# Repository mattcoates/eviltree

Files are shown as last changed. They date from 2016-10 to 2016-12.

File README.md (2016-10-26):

# Yuletronics: Electronics Club Project Michalmas 2016

This repository contains the example Yuletronics project for Electronics Club. 
You can either use git to clone it, or simply download it 
[here](https://github.com/adamgreig/yuletronics/archive/master.zip).

You'll need KiCAD to open and edit the PCB: [download it 
here](http://kicad-pcb.org/). If you can easily get a nightly build, they have 
a few nice new features.

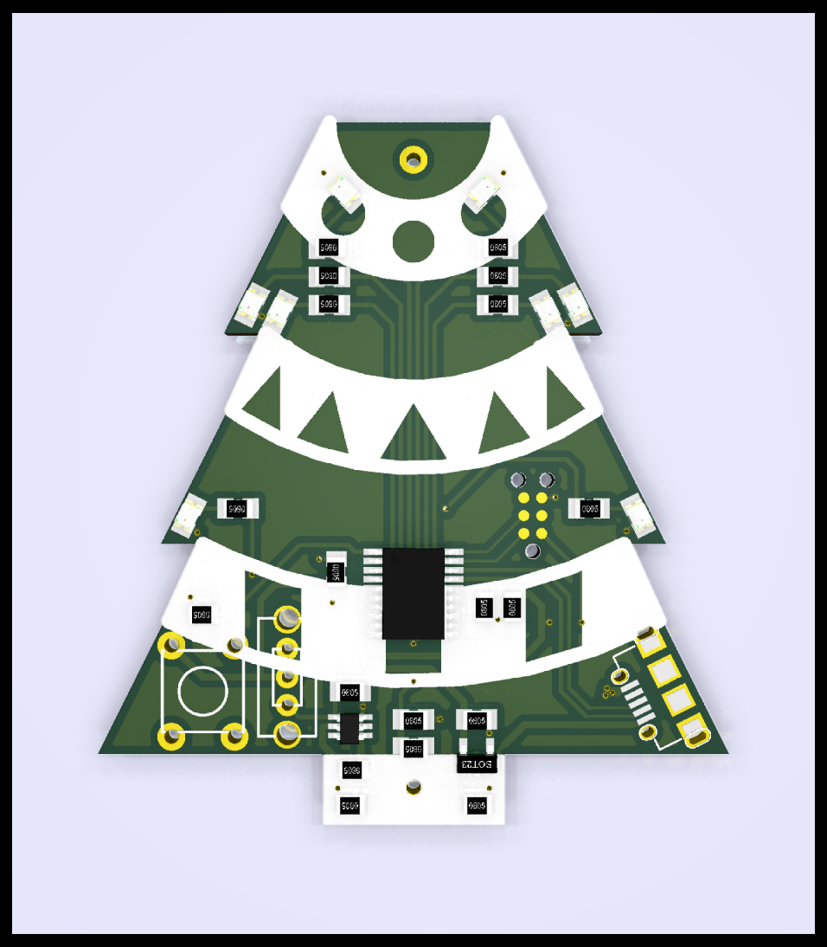
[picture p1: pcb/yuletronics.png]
3d render


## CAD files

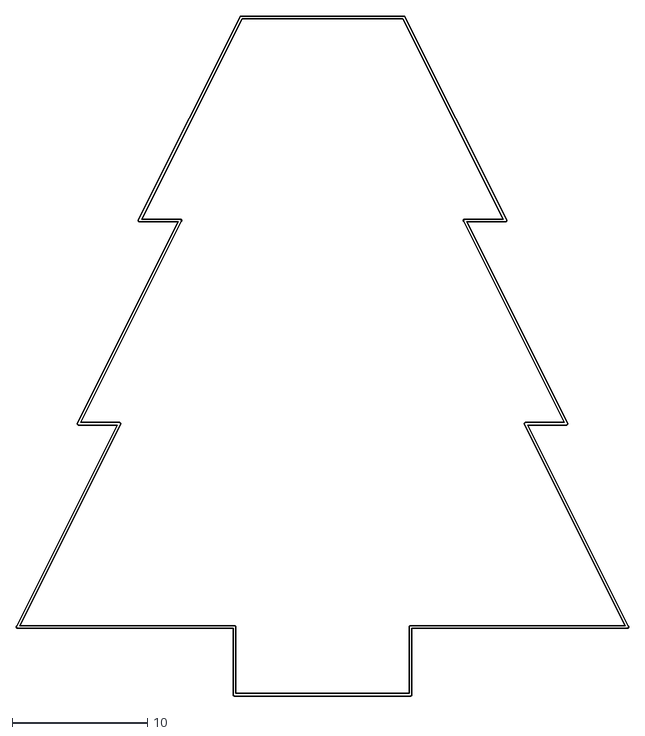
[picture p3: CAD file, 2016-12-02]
pcb/gerbers/yuletronics-Edge.Cuts.dxf
45.2 x 50.2

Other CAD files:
pcb/gerbers/yuletronics-F.Paste.dxf

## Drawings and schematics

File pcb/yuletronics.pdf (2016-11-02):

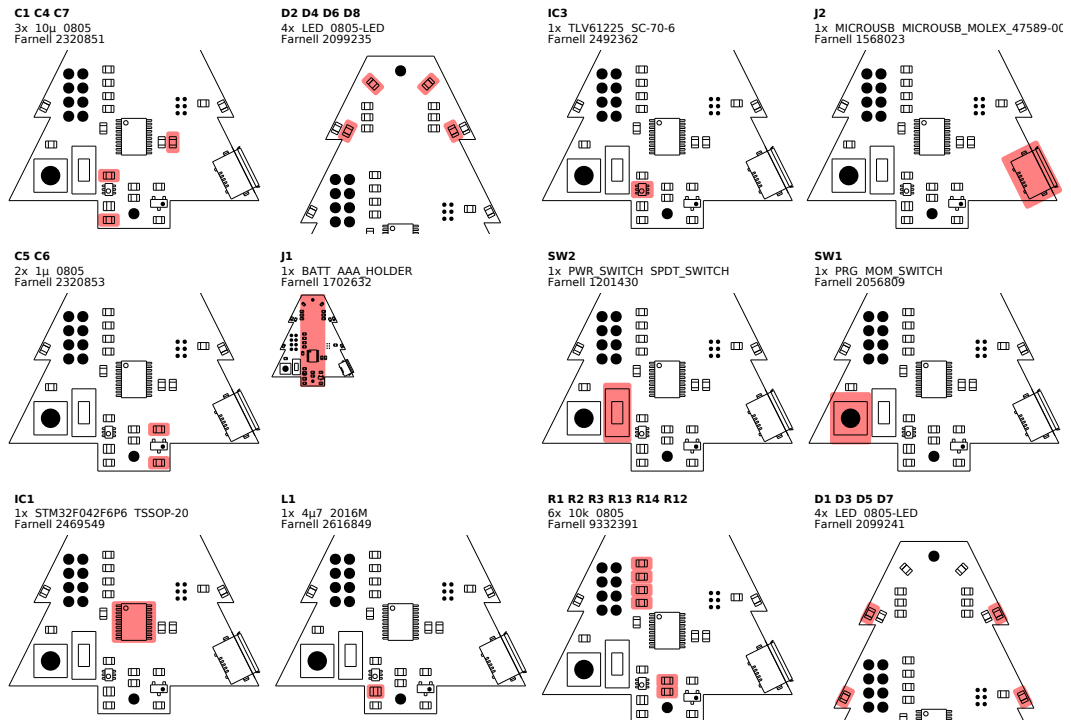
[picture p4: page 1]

C3 C2
2x 100n 0805
Farnell 1759265

IC2
1x MCP1700 SOT-23
Farnell 1296592

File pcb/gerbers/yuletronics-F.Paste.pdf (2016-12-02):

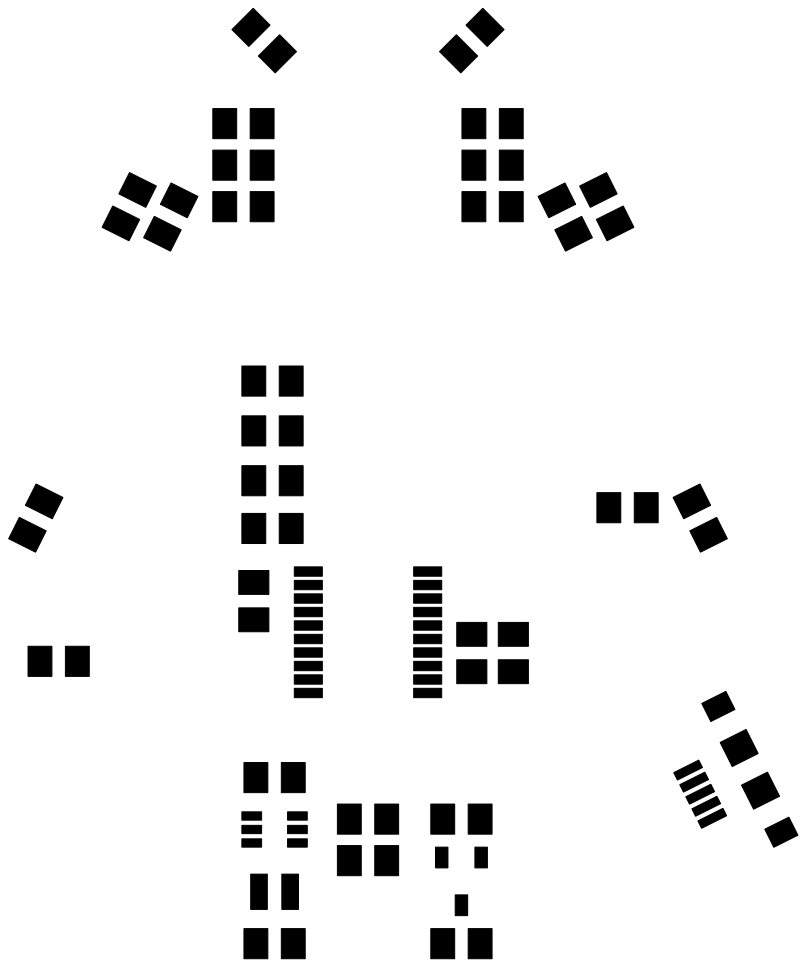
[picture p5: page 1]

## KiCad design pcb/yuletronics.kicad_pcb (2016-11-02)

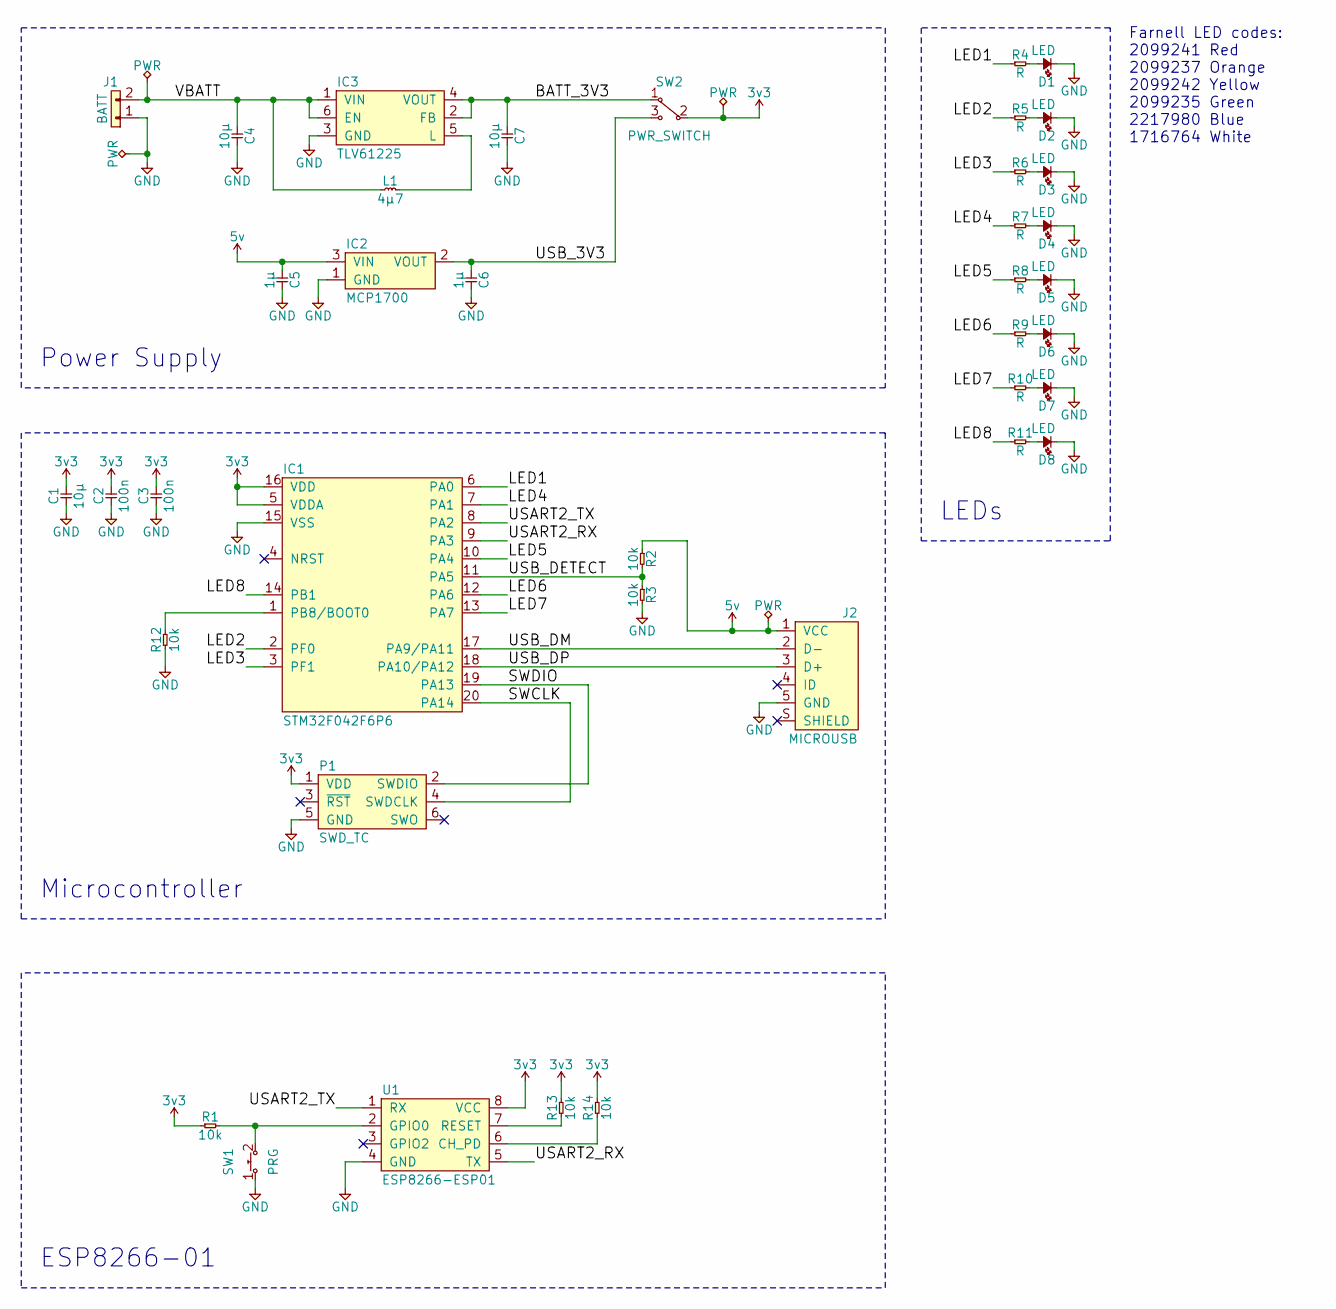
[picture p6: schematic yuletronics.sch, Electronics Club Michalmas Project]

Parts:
C1, C4, C7: 10µ; 0805; Farnell 2320851
C2, C3: 100n; 0805; Farnell 1759265
C5, C6: 1µ; 0805; Farnell 2320853
D1, D3, D5, D7: LED; 0805-LED; Farnell 2099241
D2, D4, D6, D8: LED; 0805-LED; Farnell 2099235
IC1: STM32F042F6P6; TSSOP-20; Farnell 2469549
IC2: MCP1700; SOT-23; Farnell 1296592
IC3: TLV61225; SC-70-6; Farnell 2492362
J1: BATT; AAA_HOLDER; Farnell 1702632
J2: MICROUSB; MICROUSB_MOLEX_47589-0001; Farnell 1568023
L1: 4µ7; 2016M; Farnell 2616849
P1: SWD_TC; TC2030-NL
R1, R2, R3, R12, R13, R14: 10k; 0805; Farnell 9332391
R4, R5, R6, R7, R8, R9, R10, R11: R; 0805
SW1: PRG; MOM_SWITCH; Farnell 2056809
SW2: PWR_SWITCH; SPDT_SWITCH; Farnell 1201430
U1: ESP8266-ESP01

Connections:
3v3: C1.2, C2.2, C3.2, IC1.5 (VDDA), IC1.16 (VDD), P1.1 (VDD), R1.1, R13.2, R14.2, SW2.2, U1.8 (VCC)
5v: C5.1, IC2.3 (VIN), J2.1 (VCC), R2.1
/BATT_3V3: C7.1, IC3.2 (FB), IC3.4 (VOUT), SW2.1
/LED1: IC1.6 (PA0), R4.1
/LED2: IC1.2 (PF0), R5.1
/LED3: IC1.3 (PF1), R6.1
/LED4: IC1.7 (PA1), R7.1
/LED5: IC1.10 (PA4), R8.1
/LED6: IC1.12 (PA6), R9.1
/LED7: IC1.13 (PA7), R10.1
/LED8: IC1.14 (PB1), R11.1
/SWCLK: IC1.20 (PA14), P1.4 (SWDCLK)
/SWDIO: IC1.19 (PA13), P1.2 (SWDIO)
/USART2_RX: IC1.9 (PA3), U1.5 (TX)
/USART2_TX: IC1.8 (PA2), U1.1 (RX)
/USB_3V3: C6.1, IC2.2 (VOUT), SW2.3
/USB_DETECT: IC1.11 (PA5), R2.2, R3.1
/USB_DM: IC1.17 (PA9/PA11), J2.2 (D-)
/USB_DP: IC1.18 (PA10/PA12), J2.3 (D+)
/VBATT: C4.1, IC3.1 (VIN), IC3.6 (EN), J1.2, L1.1
GND: C1.1, C2.1, C3.1, C4.2, C5.2, C6.2, C7.2, D1.1, D2.1, D3.1, D4.1, D5.1, D6.1, D7.1, D8.1, IC1.15 (VSS), IC2.1 (GND), IC3.3 (GND), J1.1, J2.5 (GND), P1.5 (GND), R3.2, R12.1, SW1.1, U1.4 (GND)
unnamed: D1.2, R4.2
unnamed: D2.2, R5.2
unnamed: D3.2, R6.2
unnamed: D4.2, R7.2
unnamed: D5.2, R8.2
unnamed: D6.2, R9.2
unnamed: D7.2, R10.2
unnamed: D8.2, R11.2
unnamed: IC1.1 (PB8/BOOT0), R12.2
unnamed: IC3.5 (L), L1.2
unnamed: R1.2, SW1.2, U1.2 (GPIO0)
unnamed: R13.1, U1.7 (RESET)
unnamed: R14.1, U1.6 (CH_PD)

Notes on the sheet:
Power Supply
Microcontroller
LEDs
Farnell LED codes: 2099241 Red 2099237 Orange 2099242 Yellow 2099235 Green 2217980 Blue 1716764 White
ESP8266-01

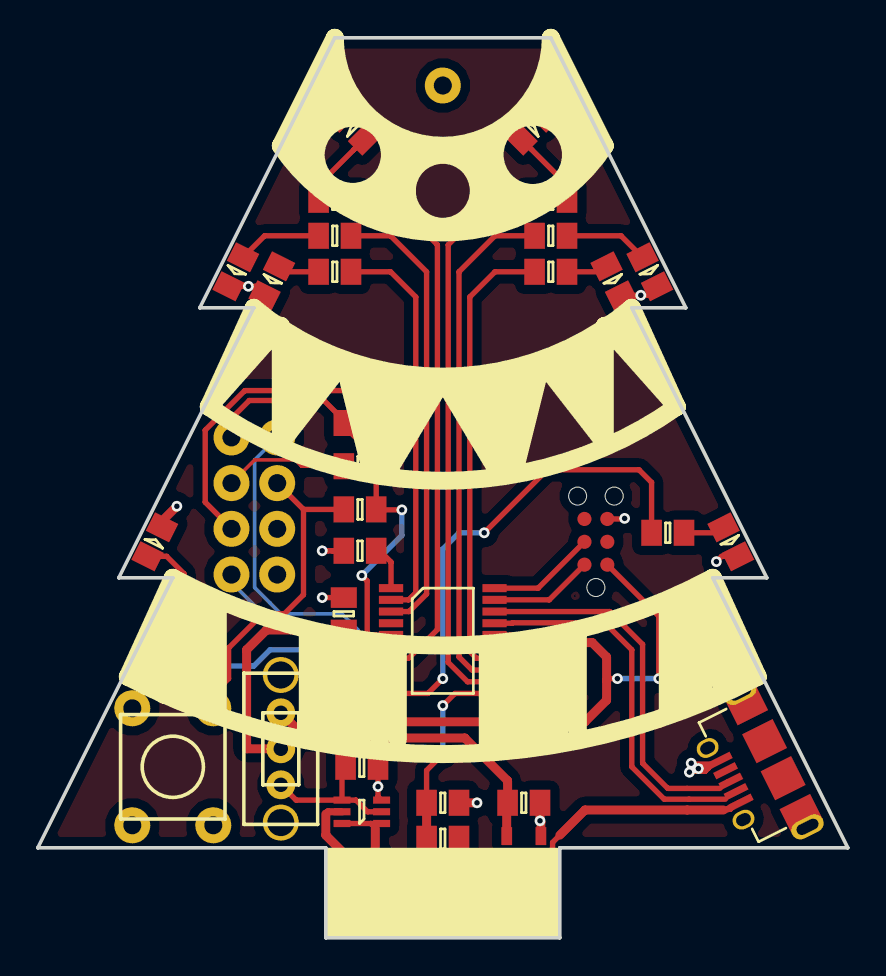
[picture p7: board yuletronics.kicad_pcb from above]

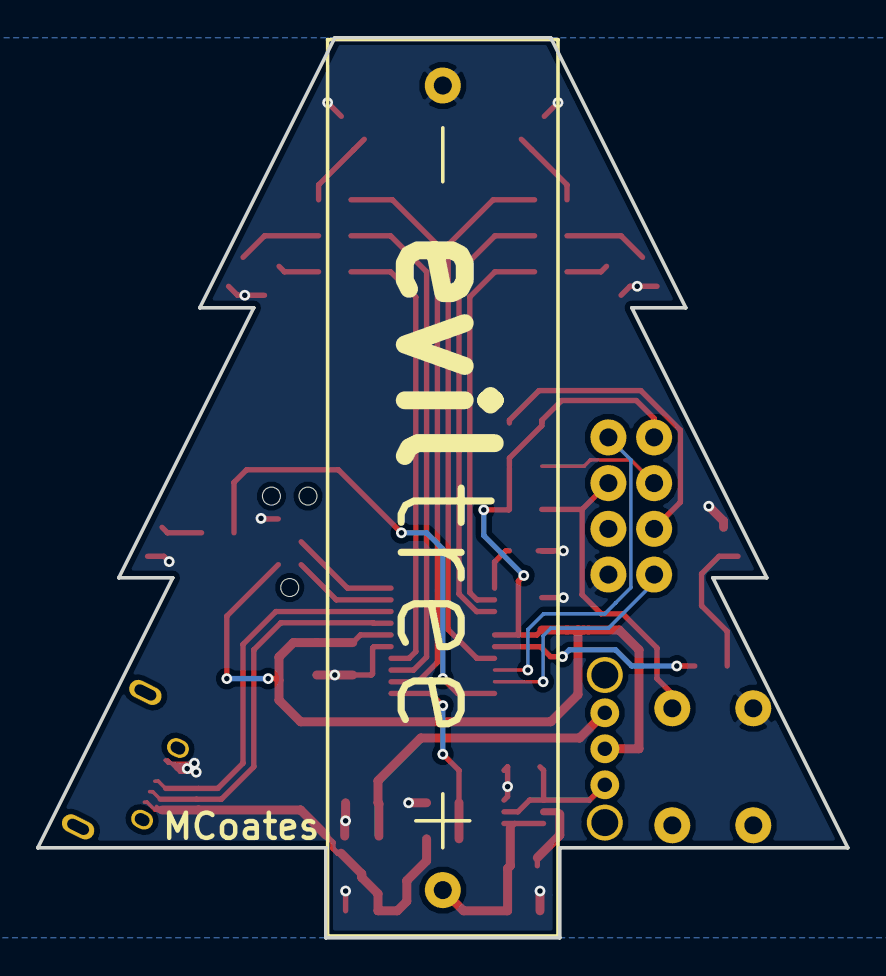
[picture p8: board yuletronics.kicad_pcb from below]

Board: 2 copper layers, 45.0 x 50.0 mm, 39 parts (2 on the bottom side), 34 nets.

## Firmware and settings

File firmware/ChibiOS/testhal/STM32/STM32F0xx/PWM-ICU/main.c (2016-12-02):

/*
    ChibiOS - Copyright (C) 2006..2015 Giovanni Di Sirio

    Licensed under the Apache License, Version 2.0 (the "License");
    you may not use this file except in compliance with the License.
    You may obtain a copy of the License at

        http://www.apache.org/licenses/LICENSE-2.0

    Unless required by applicable law or agreed to in writing, software
    distributed under the License is distributed on an "AS IS" BASIS,
    WITHOUT WARRANTIES OR CONDITIONS OF ANY KIND, either express or implied.
    See the License for the specific language governing permissions and
    limitations under the License.
*/

#include "ch.h"
#include "hal.h"

static void pwmpcb(PWMDriver *pwmp) {

  (void)pwmp;
  palClearPad(GPIOC, GPIOC_LED4);
}

static void pwmc1cb(PWMDriver *pwmp) {

  (void)pwmp;
  palSetPad(GPIOC, GPIOC_LED4);
}

static PWMConfig pwmcfg = {
  10000,                                    /* 10kHz PWM clock frequency.   */
  10000,                                    /* Initial PWM period 1S.       */
  pwmpcb,
  {
   {PWM_OUTPUT_ACTIVE_HIGH, pwmc1cb},
   {PWM_OUTPUT_DISABLED, NULL},
   {PWM_OUTPUT_DISABLED, NULL},
   {PWM_OUTPUT_DISABLED, NULL}
  },
  0,
  0
};

icucnt_t last_width, last_period;

static void icuwidthcb(ICUDriver *icup) {

  palSetPad(GPIOC, GPIOC_LED3);
  last_width = icuGetWidthX(icup);
}

static void icuperiodcb(ICUDriver *icup) {

  palClearPad(GPIOC, GPIOC_LED3);
  last_period = icuGetPeriodX(icup);
}

static void icuoverflowcb(ICUDriver *icup) {

  (void)icup;
}

static ICUConfig icucfg = {
  ICU_INPUT_ACTIVE_HIGH,
  10000,                                    /* 10kHz ICU clock frequency.   */
  icuwidthcb,
  icuperiodcb,
  icuoverflowcb,
  ICU_CHANNEL_1,
  0
};

/*
 * Application entry point.
 */
int main(void) {

  /*
   * System initializations.
   * - HAL initialization, this also initializes the configured device drivers
   *   and performs the board-specific initializations.
   * - Kernel initialization, the main() function becomes a thread and the
   *   RTOS is active.
   */
  halInit();
  chSysInit();

  /*
   * Initializes the PWM driver 2 and ICU driver 3.
   * GPIOA6 is the ICU input (CH1).
   * GPIOA8 is the PWM output (CH1).
   * The two pins have to be externally connected together.
   */
  pwmStart(&PWMD1, &pwmcfg);
  pwmEnablePeriodicNotification(&PWMD1);
  palSetPadMode(GPIOA, 8, PAL_MODE_ALTERNATE(2));
  icuStart(&ICUD3, &icucfg);
  palSetPadMode(GPIOA, 6, PAL_MODE_ALTERNATE(1));
  icuStartCapture(&ICUD3);
  icuEnableNotifications(&ICUD3);
  chThdSleepMilliseconds(2000);

  /*
   * Starts the PWM channel 0 using 75% duty cycle.
   */
  pwmEnableChannel(&PWMD1, 0, PWM_PERCENTAGE_TO_WIDTH(&PWMD1, 7500));
  pwmEnableChannelNotification(&PWMD1, 0);
  chThdSleepMilliseconds(5000);

  /*
   * Changes the PWM channel 0 to 50% duty cycle.
   */
  pwmEnableChannel(&PWMD1, 0, PWM_PERCENTAGE_TO_WIDTH(&PWMD1, 5000));
  chThdSleepMilliseconds(5000);

  /*
   * Changes the PWM channel 0 to 25% duty cycle.
   */
  pwmEnableChannel(&PWMD1, 0, PWM_PERCENTAGE_TO_WIDTH(&PWMD1, 2500));
  chThdSleepMilliseconds(5000);

  /*
   * Changes PWM period to half second the duty cycle becomes 50%
   * implicitly.
   */
  pwmChangePeriod(&PWMD1, 5000);
  chThdSleepMilliseconds(5000);

  /*
   * Disables channel 0 and stops the drivers.
   */
  pwmDisableChannel(&PWMD1, 0);
  pwmStop(&PWMD1);
  icuStopCapture(&ICUD3);
  icuStop(&ICUD3);
  palClearPad(GPIOC, GPIOC_LED3);
  palClearPad(GPIOC, GPIOC_LED4);

  /*
   * Normal main() thread activity, in this demo it does nothing.
   */
  while (true) {
    chThdSleepMilliseconds(500);
  }
  return 0;
}

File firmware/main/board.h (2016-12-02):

/*
    ChibiOS - Copyright (C) 2006..2016 Giovanni Di Sirio
    Licensed under the Apache License, Version 2.0 (the "License");
    you may not use this file except in compliance with the License.
    You may obtain a copy of the License at
    http://www.apache.org/licenses/LICENSE-2.0
    Unless required by applicable law or agreed to in writing, software
    distributed under the License is distributed on an "AS IS" BASIS,
    WITHOUT WARRANTIES OR CONDITIONS OF ANY KIND, either express or implied.
    See the License for the specific language governing permissions and
    limitations under the License.
*/

/*
    Generated by gen-board.h.py based on board.yaml
*/

#ifndef _BOARD_H_
#define _BOARD_H_


/*
    Setup for evilTree
*/

/*
    Board identifier
*/
#define BOARD_
#define BOARD_NAME                     "evilTree"

/*
    Board oscillators-related settings.
*/
#if !defined(STM32_LSECLK)
#define STM32_LSECLK                   0U
#endif

#if !defined(STM32_HSECLK)
#define STM32_HSECLK                   0U
#endif

/*
    Board voltages
    Required for performance limits calculation.
*/
#define STM32_VDD                      330U

/*
    MCU type as defined in the ST header.
*/
#define STM32F042x6

/*
    IO pins assignments.
*/

#define GPIOA_LED1                     0U
#define GPIOA_LED4                     1U
#define GPIOA_PIN2                     2U
#define GPIOA_PIN3                     3U
#define GPIOA_LED5                     4U
#define GPIOA_PIN5                     5U
#define GPIOA_LED6                     6U
#define GPIOA_LED7                     7U
#define GPIOA_PIN8                     8U
#define GPIOA_PIN9                     9U
#define GPIOA_PIN10                    10U
#define GPIOA_USB_DM                   11U
#define GPIOA_USB_DP                   12U
#define GPIOA_SWDIO                    13U
#define GPIOA_SWCLK                    14U
#define GPIOA_PIN15                    15U

#define GPIOB_PIN0                     0U
#define GPIOB_LED8                     1U
#define GPIOB_PIN2                     2U
#define GPIOB_PIN3                     3U
#define GPIOB_PIN4                     4U
#define GPIOB_PIN5                     5U
#define GPIOB_PIN6                     6U
#define GPIOB_PIN7                     7U
#define GPIOB_PIN8                     8U
#define GPIOB_PIN9                     9U
#define GPIOB_PIN10                    10U
#define GPIOB_PIN11                    11U
#define GPIOB_PIN12                    12U
#define GPIOB_PIN13                    13U
#define GPIOB_PIN14                    14U
#define GPIOB_PIN15                    15U

#define GPIOC_PIN0                     0U
#define GPIOC_PIN1                     1U
#define GPIOC_PIN2                     2U
#define GPIOC_PIN3                     3U
#define GPIOC_PIN4                     4U
#define GPIOC_PIN5                     5U
#define GPIOC_PIN6                     6U
#define GPIOC_PIN7                     7U
#define GPIOC_PIN8                     8U
#define GPIOC_PIN9                     9U
#define GPIOC_PIN10                    10U
#define GPIOC_PIN11                    11U
#define GPIOC_PIN12                    12U
#define GPIOC_PIN13                    13U
#define GPIOC_PIN14                    14U
#define GPIOC_PIN15                    15U

#define GPIOD_PIN0                     0U
#define GPIOD_PIN1                     1U
#define GPIOD_PIN2                     2U
#define GPIOD_PIN3                     3U
#define GPIOD_PIN4                     4U
#define GPIOD_PIN5                     5U
#define GPIOD_PIN6                     6U
#define GPIOD_PIN7                     7U
#define GPIOD_PIN8                     8U
#define GPIOD_PIN9                     9U
#define GPIOD_PIN10                    10U
#define GPIOD_PIN11                    11U
#define GPIOD_PIN12                    12U
#define GPIOD_PIN13                    13U
#define GPIOD_PIN14                    14U
#define GPIOD_PIN15                    15U

#define GPIOF_LED2                     0U
#define GPIOF_LED3                     1U
#define GPIOF_PIN2                     2U
#define GPIOF_PIN3                     3U
#define GPIOF_PIN4                     4U
#define GPIOF_PIN5                     5U
#define GPIOF_PIN6                     6U
#define GPIOF_PIN7                     7U
#define GPIOF_PIN8                     8U
#define GPIOF_PIN9                     9U
#define GPIOF_PIN10                    10U
#define GPIOF_PIN11                    11U
#define GPIOF_PIN12                    12U
#define GPIOF_PIN13                    13U
#define GPIOF_PIN14                    14U
#define GPIOF_PIN15                    15U

/*
    IO lines assignments.
*/
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

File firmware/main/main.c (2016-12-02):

/*
 *  EVIL CHRISTMAS TREE - Written By Matthew Coates
 */

#include "ch.h"
#include "hal.h"

/* PWM Period in Ticks */
#define PWM_PERIOD  128   

/* Function Prototypes */
static void fadeUp(uint8_t time);                       /* time = Fade Duration in (Integer) Seconds */
static void fadeDown(uint8_t time);

/* PWM Callback Functions */
static void pwmpcb(PWMDriver *pwmp) {

  (void)pwmp;
  palSetPad(GPIOA, GPIOA_LED5);
  palSetPad(GPIOF, GPIOF_LED2);
  palSetPad(GPIOF, GPIOF_LED3);
}

static void pwmc1cb(PWMDriver *pwmp) {

  (void)pwmp;
  palClearPad(GPIOA, GPIOA_LED5);
  palClearPad(GPIOF, GPIOF_LED2);
  palClearPad(GPIOF, GPIOF_LED3);
}

/* PWM Channel 2 Config */
static PWMConfig pwm2cfg = {
  10000,                                /* 10kHz Timer Clock */                                    
  PWM_PERIOD,                                    
  pwmpcb,
  {
   {PWM_OUTPUT_ACTIVE_HIGH, pwmc1cb},
   {PWM_OUTPUT_ACTIVE_HIGH, NULL},
   {PWM_OUTPUT_DISABLED, NULL},
   {PWM_OUTPUT_DISABLED, NULL}
  },
  0,
  0
};

/* PWM Channel 3 Config */
static PWMConfig pwm3cfg = {
  10000,                                /* 10kHz Timer Clock */
  PWM_PERIOD,       
  NULL,
  {
   {PWM_OUTPUT_ACTIVE_HIGH, NULL},
   {PWM_OUTPUT_ACTIVE_HIGH, NULL},
   {PWM_OUTPUT_DISABLED, NULL},
   {PWM_OUTPUT_ACTIVE_HIGH, NULL}
  },
  0,
  0
};

/* LED Pattern Thread */
static THD_WORKING_AREA(wa_LED, 256);
static THD_FUNCTION(thd_LED, arg) {

    (void)arg;
    chRegSetThreadName("LED");
      
    /* LED Sequence */
    while(TRUE) {
        fadeUp(8);
        fadeDown(8);
    }
}


/* Application Entry Point */
int main(void) {

    /* System Init */
    halInit();
    chSysInit();
    
    /* PWM Init */
    pwmStart(&PWMD2, &pwm2cfg);
    pwmStart(&PWMD3, &pwm3cfg);  
    pwmEnablePeriodicNotification(&PWMD2);
    pwmEnableChannelNotification(&PWMD2, 0);
    
    /* Create LED Pattern Thread */
    chThdCreateStatic(wa_LED, sizeof(wa_LED), NORMALPRIO, thd_LED, NULL);

    /* Do Nothing */
    while (true) {
        chThdSleepMilliseconds(1000);
    }
}

static void fadeUp(uint8_t time) {
    
    uint16_t percent = 1000;
    
    while (percent < 10000) {
            
        /* Set PWM Duty Cycle */
        pwmEnableChannel(&PWMD2, 0, PWM_PERCENTAGE_TO_WIDTH(&PWMD2, percent));
        pwmEnableChannel(&PWMD2, 1, PWM_PERCENTAGE_TO_WIDTH(&PWMD2, percent));    
        pwmEnableChannel(&PWMD3, 0, PWM_PERCENTAGE_TO_WIDTH(&PWMD3, percent));
        pwmEnableChannel(&PWMD3, 1, PWM_PERCENTAGE_TO_WIDTH(&PWMD3, percent));
        pwmEnableChannel(&PWMD3, 3, PWM_PERCENTAGE_TO_WIDTH(&PWMD3, percent));
        
        /* Update Loop Counter */
        percent = percent + 10;
        chThdSleepMilliseconds(time);
    }
}


static void fadeDown(uint8_t time) {
    
    uint16_t percent = 10000;
    
    while (percent > 1000) {
            
        /* Set PWM Duty Cycle */
        pwmEnableChannel(&PWMD2, 0, PWM_PERCENTAGE_TO_WIDTH(&PWMD2, percent));
        pwmEnableChannel(&PWMD2, 1, PWM_PERCENTAGE_TO_WIDTH(&PWMD2, percent));    
        pwmEnableChannel(&PWMD3, 0, PWM_PERCENTAGE_TO_WIDTH(&PWMD3, percent));
        pwmEnableChannel(&PWMD3, 1, PWM_PERCENTAGE_TO_WIDTH(&PWMD3, percent));
        pwmEnableChannel(&PWMD3, 3, PWM_PERCENTAGE_TO_WIDTH(&PWMD3, percent));
        
        /* Update Loop Counter */
        percent = percent - 10;
        chThdSleepMilliseconds(time);
    }
}

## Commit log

2016-10-26 Initial Download
    [yuletronics-B.Cu.gbl, yuletronics-B.Mask.gbs, yuletronics-B.SilkS.gbo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]
2016-10-26 Added ESP
    [yuletronics.kicad_pcb, yuletronics.sch]
2016-10-26 Export Gerbers
    [yuletronics-B.Cu.gbl, yuletronics-B.Mask.gbs, yuletronics-B.SilkS.gbo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]
2016-11-02 Final Changes
    [yuletronics-B.Cu.gbl, yuletronics-B.Mask.gbs, yuletronics-B.SilkS.gbo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]
2016-12-02 Firmware things
    [stm_spc56ec74a256s_spc56ec74_minimodule_debug_jtag.cfg, stm_xpc560b64_minimodule_debug_jtag.cfg, stm_xpc560b_spc560d40_minimodule_debug_jtag.cfg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]
